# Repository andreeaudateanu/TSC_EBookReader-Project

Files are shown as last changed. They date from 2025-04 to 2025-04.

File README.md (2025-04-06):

# Proiect TSC - E-Book Reader
## Udățeanu Andreea-Laura

Acest proiect reprezinta un sistem embedded de tip **E-Book Reader**, bazat pe microcontrollerul **ESP32-C6**. Dispozitivul este capabil sa afiseze continut text pe un ecran **E-Paper**, oferind o solutie cu consum redus de energie, ideala pentru citirea offline a documentelor. Sistemul include, de asemenea, functionalitati precum citire de pe card SD, afisare dinamica, butoane pentru control si conectivitate extinsa prin interfata I2C.

# Diagrama bloc

Diagrama Bloc

# Functionalitati Hardware

Proiectul utilizeaza microcontrollerul **ESP32-C6-WROOM-1-N8**, un modul avansat cu suport pentru **Wi-Fi 6**, **Bluetooth Low Energy 5.0** si arhitectura **RISC-V**:

## Microcontrollerul ESP32-C6

- Modul avansat cu suport pentru **Wi-Fi 6**, **Bluetooth Low Energy 5.0** si arhitectura **RISC-V**
- **Interfete:** SPI, I2C, UART, USB, PWM, GPIO
	- **SPI (Serial Peripheral Interface):** este utilizat pentru comunicatia rapida cu dispozitive precum E-Paper Display-ul, memoria NOR Flash si cardul microSD.
	- **I2C (Inter-Integrated Circuit):** este o magistrala seriala bidirectionala cu doi pini (SDA si SCL), folosita pentru conectarea senzorului BME688, RTC-ului DS3231SN si monitorului de baterie MAX17048.
	- **UART (Universal Asynchronous Receiver/Transmitter):** interfata seriala folosita pentru comunicatie cu terminalul serial (TX/RX).
	- **GPIO (General Purpose Input/Output):** pini de uz general configurati ca intrare/iesire digitala – utilizati pentru butoane, controlul ecranului E-Ink, etc.

- **Caracteristici speciale:** ofera suport pentru moduri de economisire (deep sleep)
- **Conexiuni:** Interfata centrala – conecteaza toate modulele externe din cadrul proiectului(E-Paper, SD card, senzori, RTC, memorie NOR Flash, etc.)

## Alimentare si protectie

### MAX17048 – Monitorizare nivel de baterie Li-Po
- **Comunicare:** prin interfata I2C cu ESP32-C6 (SCL, SDA)
- **Iesire:** are la iesire un semnal ALERT pentru nivel critic baterie

### MCP73831 – Controller de incarcare a bateriei Li-Po
- **Incarcare:** utilizeaza o celula Li-Po prin USB (VBUS) → 4.2V
- **Curent de incarcare:** pana la 500 mA
- **LED-uri:** care indica starea de incarcare (CHG_LED)

### XC6220A331MR-G – Regulator de tensiune LDO
- Primeste la intrare 5V prin USB (VBUS), iar la iesire transmite o tensiune de 3.3V
- **Curent maxim:** 200 mA
- **Consum standby:** <1 µA

### Conector USB-C si Protectie ESD
- **Conector USB-C:** utilizat atat pentru alimentarea dispozitivului (VBUS) cat si pentru comunicatie USB cu microcontrollerul ESP32-C6.

- **Protectie ESD:** implementata pe liniile de date si alimentare folosind diode TVS dedicate:
USBLC6-2SC6Y – protejeaza liniile D+ si D−. PMF0501 – asigura protectie suplimentara pe linia de alimentare VBUS.
- **Utilizare:** permite incarcarea bateriei prin controllerul MCP73831, dar si programarea/diagnosticarea ESP32-C6 fara conexiuni suplimentare.

## Stocare

### SD Card
- **Functie:** citire/scriere a fisierelor E-Book din cardul microSD
- **Interfata:** SPI partajata cu E-Paper
- **Semnale:** SS_SD, MOSI, MISO, SCK
- **Slot:** 112A-TAAR-R03

### W25Q512JVEIQ – Memorie NOR Flash externa 64MB
- **Capacitate:** 64 MB
- **Interfata:** conectata la magistrala SPI (nu partajeaza cu E-Paper)
- **Semnale:** FLASH_CS, MOSI, MISO, SCK
- **Functie:** stocare fonturi, imagini, firmware, configurari

## Afisaj E-Paper

- Interfete SPI si GPIO dedicate, avand semnale precum: CS (EPD_CS), DC (EPD_DC), RST (EPD_RST), BUSY (EPD_BUSY), MOSI, SCK  
## **Header special EPD** cu 20 pini
## **Controlul alimentarii EPD:** 
Permite microcontrollerului sa activeze sau sa dezactiveze alimentarea modulului E-Paper pentru a economisi energie, avand la iesire o tensiune de 3V3
## **Selectare mod:** 
Comutator tip jumper pentru a selecta tipul de display (circuit EPD driver dedicat)
- Consum 0 in standby, ideal pentru afisaj static

## Senzor de Mediu BME688
- **Functionalitati:** temperatura, umiditate, presiune, calitate aer (VOC)
- **Interfata:** I2C
- **Pini:** SDA, SCL legati la magistrala I2C comuna
- **Tensiune de alimentare:** 3.3V

## Modul RTC – DS3231SN
- **Functie:** surprinde timpul real cu precizie ±2ppm, avand suport deep sleep
- **Conexiune:** I2C – partajeaza pinii SDA/SCL cu senzorul BME688 si cu monitorizatorul de baterie MAX17048
- **Iesiri:** semnal 32kHz si semnal de intrerupere (INT_RTC)
- **Alimentare:** 3.3V, avand si backup intern (capacitor)

## Functii de control, reset si protectie

### Butoane de Control
- **BOOT / RESET si IO/CHANGE personalizat:** conectate pe GPIO cu retele RC
- **Functii:** BOOT: initializare microcontroller in modul bootloader, RESET: resetare generala a sistemului si IO/CHANGE: buton suplimentare pentru interactiuni custom de tipul schimbarii paginii, a meniului, etc.

### BD5229G-TR – Voltage Supervisor
- **Rol:** detecteaza scaderile de tensiune (brown-out) sub un anumit prag critic si genereaza automat un semnal de rest
- **Asigura o pornirea sigura a sistemului

### Protectii ESD si Interfete Extensibile

- **Linii protejate:** toate magistralele sensibile – USB, SPI, I2C si GPIO – sunt protejate impotriva descarcarilor electrostatice (ESD) prin diode (ex: **USBLC6-2SC6Y**, **PGB1010603MR**, **MBR0530**).
- **Conector Qwiic / Stemma QT:** ofera o interfata I2C standard (3.3V, GND, SDA, SCL) pentru extinderea rapida a sistemului cu senzori si periferice de la SparkFun sau Adafruit, fara necesitatea lipirii.
- **Paduri de test:** sunt incluse pe PCB pentru depanare usoara, verificari de semnal si programare.

### Consum de energie estimativ

| Componenta | Consum aproximativ |
|:---|:---|
| ESP32-C6 | 120–150 mA |
| E-Paper Display | 20–40 mA |
| Senzor BME688 | 1–2 mA |
| RTC DS3231SN | 200 µA |
| SD Card | 40–100 mA |
| MAX17048 | 50 µA |
| NOR Flash (W25Q512JVEIQ)  | 20 mA |
| Total sistem - mod activ  | aprob. 300 mA |
| Total sistem - deep sleep | max. 10 µA |

Daca nu sunt dezactivate toate modulele fizic (cu MOSFET sau power gate), deep sleep-ul poate ajunge usor la 1–2 mA, deci <10 µA este ideal si atins doar cu management riguros al energiei.

### Alocarea pinilor

## E-Paper Display

| Pin ESP32-C6 | Functie | Utilizare |
|---|---|---|
| IO3  (26) | EPD_BUSY | Semnalizează dacă ecranul este activ |
| IO5  (5) | EPD_DC | Schimba modul intre date și comanda |
| IO6  (6) | SCK | Linie de ceas SPI - transfer de date |
| IO7  (7) | MOSI | Trimitere date către ecran prin SPI |
| IO10 (11) | EPD_CS | Activare comunicație cu modulul EPD |
| IO23 (21) | EPD_RST | Resetare ecran |
| IO20 (18) | EPD_3V3_C | Control tensiune de alimentare 3V3 EPD  |

## Magistrala I2C (MAX17048, RTC DS3231, BME688)

| Pin ESP32-C6 | Functie | Utilizare |
|---|---|---|
| IO21 (19) | SDA | Linie de transmitere date I2C |
| IO22 (20) | SCL | Linie de ceas I2C |
| IO19 (17) | I2C_PW | Pornire/oprire senzori I2C |

## Modul RTC DS3231SN

| Pin ESP32-C6 | Functie | Utilizare |
|---|---|---|
| IO0 (8) | INT_RTC | Semnal de întrerupere RTC |
| IO1 (9) | 32KHz | Iesire ceas precis |
| IO18 (16) | RTC_RST | Resetare hardware al modulului RTC |

## USB
| Pin ESP32-C6 | Functie | Utilizare |
|---|---|---|
| IO12 (13) | USB_D- | Linia negativa de comunicatie USB |
| IO13 (14) | USB_D+ | Linia pozitiva de comunicatie USB |

## Seriala UART

| Pin ESP32-C6 | Functie | Utilizare |
|---|---|---|
| IO16 (25) | TX | Transmisie UART |
| IO17 (24) | RX | Receptie UART |

## SD Card

| Pin ESP32-C6 | Functie | Utilizare |
|---|---|---|
| IO2 (27) | MISO | Receptie date |
| IO4 (4) | SS_SD | Selectare modul SD |
| IO6 (6) | SCK | Ceas SPI |
| IO7 (7) | MOSI | Transmisie date |

## Memorie Externa NOR Flash 64MB

| Pin ESP32-C6 | Functie | Utilizare |
|---|---|---|
| IO11 (12) | FLASH_CS | Selectare chip NOR |
| IO2  (27) | MISO | Receptie date |
| IO6  (6) | SCK | Ceas SPI |
| IO7  (7) | MOSI | Transmisie date |

## Butoane

| Pin ESP32-C6 | Functie | Utilizare |
|---|---|---|
| EN (3) | RESET | Resetare microcontroller |
| IO8  (10) | IO/BOOT | Buton BOOT (în modul de programare) |
| IO15 (23) | IO/CHANGE | Buton custom pentru diverse actiuni |

## Alimentare si Masă

| Pin ESP32-C6 | Functie | Utilizare |
|---|---|---|
| Pin 2 | 3V3 | Alimentare principala la 3.3V |
| Pin 1 | GND | Conectare la masa |

## Bill of Materials

| Componenta | Link Cumpărare | Datasheet |
|---|---|---|
| Condensatoare Tantalum | [Buy](https://ro.mouser.com/ProductDetail/KYOCERA-AVX/TAJW107M010RNJ?qs=Wtp%252Bf%2FAeVqIH8v1VxV%252B1Rg%3D%3D) | [Datasheet](https://ro.mouser.com/datasheet/2/40/TAJ-3165264.pdf) |
| Rezistente R0402 | [Buy](https://store.comet.srl.ro/Search/?keywords=r0402#eyJpcHAiOiIyMCIsIm0iOiIiLCJrIjoicjA0MDIifQ%3D%3D) | [Datasheet](https://www.yageo.com/upload/media/product/products/datasheet/rchip/PYu-RC_Group_51_RoHS_L_12.pdf) |
| Condensatoare C0402 | [Buy](https://store.comet.srl.ro/CatalogueFarnell/Search/?keywords=c0402#eyJpcHAiOiIyMCIsImsiOiJjMDQwMiJ9) | [Datasheet](https://componentsearchengine.com/Datasheets/2/CC0402MRX5R5BB106.pdf) |
| 112A-TAAR-R03 | [Buy](https://store.comet.srl.ro/Catalogue/Product/43497/) | [Datasheet](https://www.snapeda.com/parts/112A-TAAR-R03/Attend/datasheet/) |
| SD0805S020S1R0 | [Buy](https://ro.mouser.com/ProductDetail/KYOCERA-AVX/SD0805S020S1R0?qs=jCA%252BPfw4LHbpkAoSnwrdjw%3D%3D) | [Datasheet](https://ro.mouser.com/datasheet/2/40/schottky-3165252.pdf) |
| MBR0530 | [Buy](https://ro.mouser.com/ProductDetail/onsemi-Fairchild/MBR0530?qs=VOMQJJE%252BBNniwJKcE3T43Q==) | [Datasheet](https://ro.mouser.com/datasheet/2/308/MBR0530_D-1810985.pdf) |
| CHG_LED | [Buy](https://ro.mouser.com/ProductDetail/Kingbright/KP-1608SURCK?qs=2JU0tDl2GZ3FuyEWfBV1%2Fg==) | [Datasheet](https://www.snapeda.com/parts/KP-1608SURCK/Kingbright/datasheet/) |
| USBLC6-2SC6Y | [Buy](https://ro.mouser.com/ProductDetail/STMicroelectronics/USBLC6-2SC6Y?qs=gNDSiZmRJS%2FOgDexvXkdow%3D%3D) | [Datasheet](https://ro.mouser.com/datasheet/2/389/usblc6_2sc6y-1852505.pdf) 
| PGB1010603MR | [Buy](https://www.digikey.com/en/products/detail/littelfuse-inc/PGB1010603MR/715755) | [Datasheet](https://www.littelfuse.com/assetdocs/pulseguard-esd-suppressors-pgb1-datasheet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) |
| ESP32-C6-WROOM-1-N8 | [Buy](https://ro.mouser.com/ProductDetail/Espressif-Systems/ESP32-C6-WROOM-1-N8?qs=8Wlm6%252BaMh8ST02Gmwp74cw%3D%3D) | [Datasheet](https://ro.mouser.com/datasheet/2/891/Espressif_ESP32_C6_WROOM_1__Datasheet_V0_1_PRELIMI-3239987.pdf) |
| DS3231SN | [Buy](https://store.comet.srl.ro/Catalogue/Product/47690/) | [Datasheet](https://ro.mouser.com/datasheet/2/609/DS3231-3421123.pdf) |
| BME680 | [Buy](https://ro.mouser.com/ProductDetail/Bosch-Sensortec/BME688?qs=IS%252B4QmGtzzqQoVDscqwx3A%3D%3D) | [Datasheet](https://ro.mouser.com/datasheet/2/783/bst_bme688_fl000-2307034.pdf) |
| MAX17048 | [Buy](https://ro.mouser.com/ProductDetail/Analog-Devices-Maxim-Integrated/MAX17048G%2bT10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) | [Datasheet](https://ro.mouser.com/datasheet/2/609/MAX17048_MAX17049-3469099.pdf) |
| MCP73831 | [Buy](https://ro.mouser.com/ProductDetail/Microchip-Technology/MCP73831T-2ATI-OT?qs=yUQqVecv4qsZbioEUu%252B83g%3D%3D) | [Datasheet](https://ro.mouser.com/datasheet/2/268/MCP73831_Family_Data_Sheet_DS20001984H-3441711.pdf) |
| BD5229G-TR | [Buy](https://www.digikey.com/en/products/detail/rohm-semiconductor/BD5229G-TR/3663792) | [Datasheet](https://fscdn.rohm.com/en/products/databook/datasheet/ic/power/voltage_detector/bd52xxg-e.pdf) |
| W25Q512JVEIQ | [Buy](https://ro.mouser.com/ProductDetail/Winbond/W25Q512JVEIQ?qs=l7cgNqFNU1jw6svr3at6tA%3D%3D) | [Datasheet](https://ro.mouser.com/datasheet/2/949/Winbond_W25Q512JV_Datasheet-3240039.pdf) |
| XC6220A331MR-G | [Buy](https://ro.mouser.com/ProductDetail/Torex-Semiconductor/XC6220A331MR-G?qs=AsjdqWjXhJ8ZSWznL1J0gg%3D%3D) | [Datasheet](https://ro.mouser.com/datasheet/2/760/xc6220-3371556.pdf) |
| USB4110-GF-A | [Buy](https://ro.mouser.com/ProductDetail/GCT/USB4110-GF-A?qs=KUoIvG%2F9IlYiZvIXQjyJeA%3D%3D) | [Datasheet](https://ro.mouser.com/datasheet/2/837/GCT_USB4110_Product_Drawing___20k_cycles-3455479.pdf) |
| FH34SRJ | [Buy](https://ro.mouser.com/ProductDetail/Hirose-Connector/FH34SRJ-24S-0.5SH99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) | [Datasheet](https://ro.mouser.com/datasheet/2/185/FH34SRJ_24S_0_5SH_99__CL0580_1255_6_99_2DDrawing_0-1615044.pdf) |
| QWIIC_RIGHT_ANGLE | [Buy](https://ro.mouser.com/ProductDetail/SparkFun/PRT-14417?qs=wd5RIQLrsJhgdz%2FpmZ%2F3GQ==) | [Datasheet](https://ro.mouser.com/datasheet/2/813/Qwiic_Connector_Datasheet-1223982.pdf) |
| Bobine 744043680 | [Buy](https://ro.mouser.com/ProductDetail/Wurth-Elektronik/744043680?qs=PGXP4M47uW6VkZq%252BkzjrHA%3D%3D) | [Datasheet](https://www.we-online.com/components/products/datasheet/744043680.pdf) |
| Si1308EDL-T1-GE3 | [Buy](https://www.digikey.com/en/products/detail/vishay-siliconix/SI1308EDL-T1-GE3/4876435) | [Datasheet](https://www.vishay.com/docs/63399/si1308edl.pdf) |
| PFMF.050.1 | [Buy](https://ro.mouser.com/ProductDetail/EPCOS-TDK/B72520T0350K062?qs=dEfas%2FXlABIszF52uu7vrg%3D%3D) | [Datasheet](https://www.tdk-electronics.tdk.com/inf/75/db/CTVS_14/Surge_protection_series.pdf) |
| DMG2305UX-7 | [Buy](https://www.digikey.com/en/products/detail/diodes-incorporated/DMG2305UX-7/4340666) | [Datasheet](https://www.diodes.com/assets/Datasheets/DMG2305UX.pdf) |
| SJ (Solder Jumpers) | [Buy](https://grabcad.com/library/solder-jumpers-1) | [Datasheet](https://grabcad.com/library/solder-jumpers-1) |
| Butoane | [Buy](https://industry.panasonic.com/global/en/products/control/switch/light-touch/number/evqpuj02k) | [Datasheet](https://industry.panasonic.com/global/en/downloads?tab=catalog&small_g_cd=203&part_no=EVQPUJ02K) |
| CPH3225A | [Buy](https://www.digikey.com/en/products/detail/seiko-instruments/CPH3225A/8692444) | [Datasheet](https://mm.digikey.com/Volume0/opasdata/d220001/medias/docus/6537/rev05-CPHCPM.pdf) |

## Concluzii si observatii privind realizarea designului hardware
- In realizarea designului am urmarit respectarea regulilor impuse de ERC si DRC specifice. Amplasarea componentelor a fost facuta tinand cont atat de documentatiile tehnice oferite (dimensiuni si recomadari de plasare a componentelor), cat si de considerente legate de rutare si functionare optima a dispozitivului.
- Pentru evitarea erorilor in cadrul PCB-ului, am ajustat dimensiunile unor footprint-uri si am corectat pad-urile pentru a indeplini regulile de buna functionare. Am folosit regulile din checklist-ul de proiectare (inclusiv asezarea condensatorilor de decuplare plasati cat mai aproape de pinii VCC ai circuitelor integrate).
- Am distribuit traseele atat pe stratul top, cat si pe stratul bottom, incercand sa obtin cat mai putine vias-uri pe traseele de alimentare, pentru a reduce posibilitatea unei caderea de tensiune. Am rutat traseele de alimentare cu o latime de 0.3 mm, traseele de semnal avand latime de 0.15 mm conform cerintelor.
- Test pad-urile au fost amplasate cat mai eficient in zone relevante, la marginea placii: langa Header-ul E-Paper-ului si langa microcontroller.
- Am orientat antena modulului ESP32-C6 spre exteriorul placii, iar sub aceasta a fost lasata o zona decupata, conform recomandarilor pentru functionare optima a conexiunii wireless.
- Am pozitionat componentele cat mai bine pentru a putea fi integrate in carcasa proiectata, urmarind atat potrivirea mecanica, cat si o utilizare eficienta a spatiului disponibil. Am amplasat bateria in zona libera ramasa, astfel incat sa nu se intersecteze cu alte componente.
- Am tinut cont de amplasarea elementelor in functie de conectorul USB-C pentru asigurarea compatibilitatii cu carcasa. Butoanele au fost plasate cat mai eficient pentru a permite accesul la acestea si integrarea cu carcasa.
- In ansamblu, designul rezultat respecta cerintele functionale si mecanice, existand un echilibru intre robustete si eficienta.

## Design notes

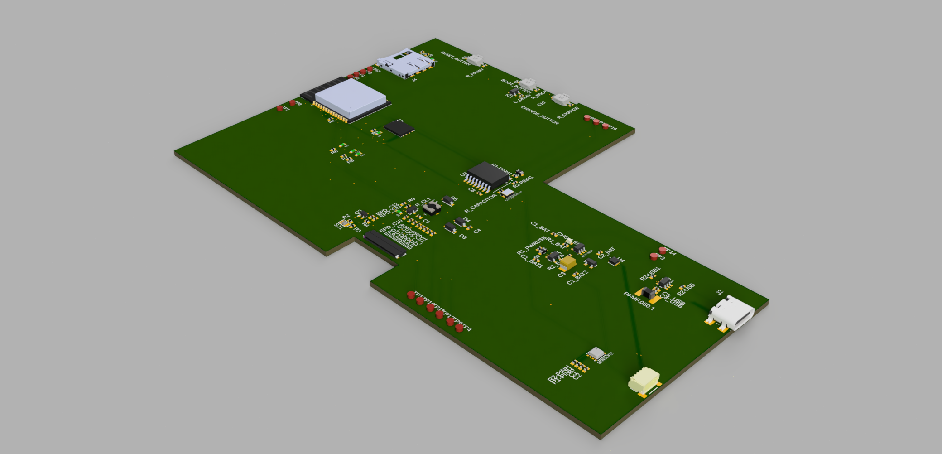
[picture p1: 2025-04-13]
Images/E-Book_Reader_Schematic_PLACUTA_HOME.png

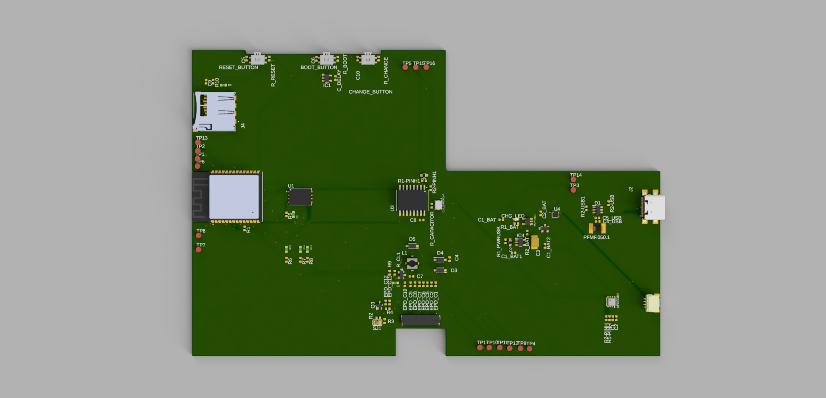
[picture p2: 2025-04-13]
Images/E-Book_Reader_Schematic_PLACUTA_TOP.png

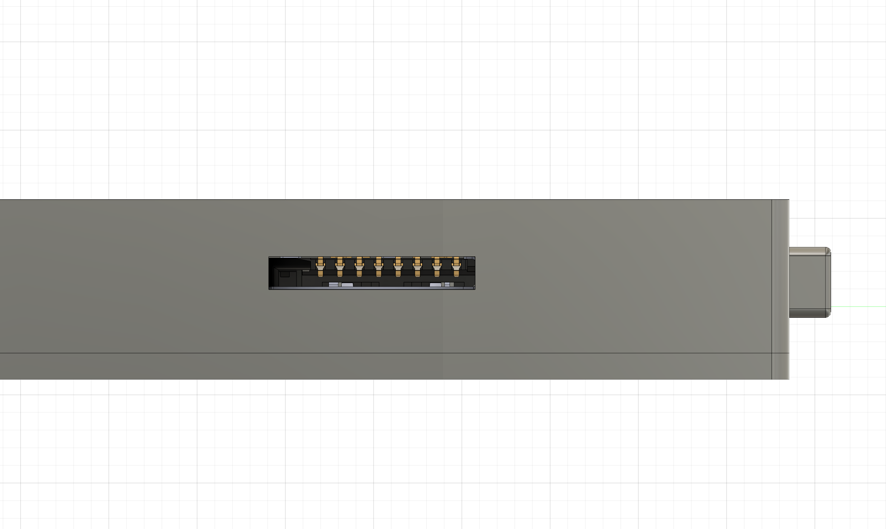
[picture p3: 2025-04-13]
Images/DeviceLeft.png

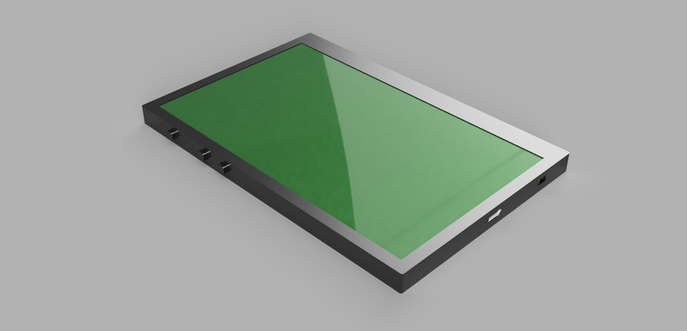
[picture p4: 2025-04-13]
Images/DeviceHome.png

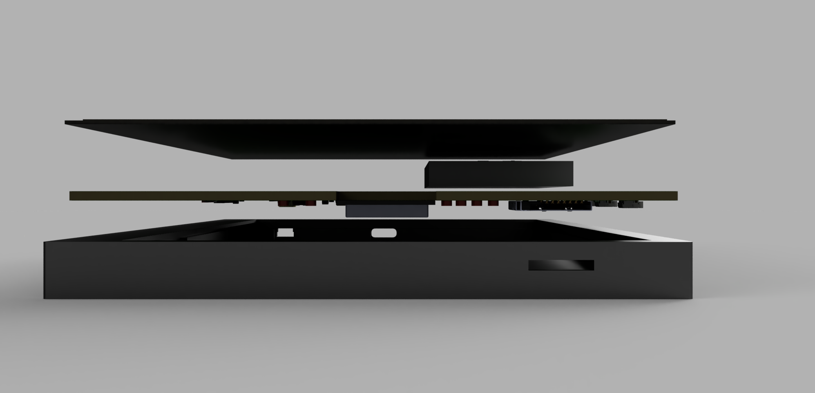
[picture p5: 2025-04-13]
Images/DeviceLayers.png

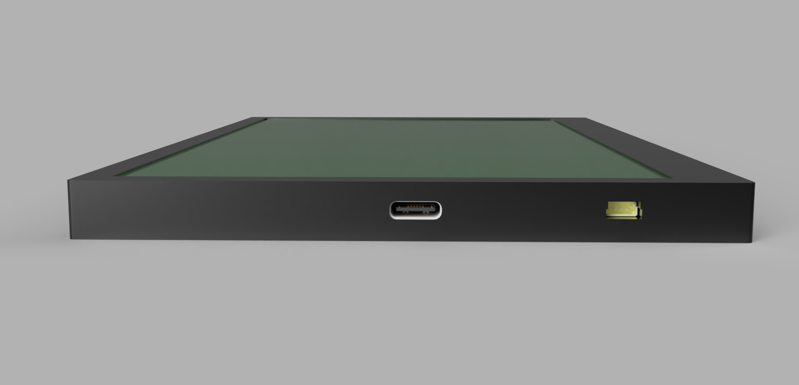
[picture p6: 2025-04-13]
Images/3D_RIGHT.png

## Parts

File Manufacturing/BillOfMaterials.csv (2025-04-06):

Part | Value | Device | Package | Description | ARROW_PART_NUMBER | ARROW_PRICE-STOCK | AVAILABILITY | CHECK_PRICES | COPYRIGHT | DESCRIPTION | HEIGHT | MANUFACTURER_NAME | MANUFACTURER_PART_NUMBER | MF | MFR_NAME | MOUSER_PART_NUMBER | MOUSER_PRICE-STOCK | MOUSER_TESTING_PART_NUMBER | MOUSER_TESTING_PRICE-STOCK | MP | PACKAGE | POPULARITY | PRICE | PROD_ID | PURCHASE-URL | SNAPEDA_LINK | SPICEMODEL | SPICEPREFIX | VALUE
BOOT_BUTTON | BUTTON_CUSYOMV1 | BUTTON_CUSYOMV1 | MYBUTTON
C1 | 100nF | EAGLE-LTSPICE_CC0402 | EAGLE-LTSPICE_C0402 | CAPACITOR, European symbol |  |  |  |  |  |  |  |  |  |  |  |  |  |  |  |  |  |  |  |  |  |  | NONE | C
C1_BAT | 4.7uF | EAGLE-LTSPICE_CC0402 | EAGLE-LTSPICE_C0402 | CAPACITOR, European symbol |  |  |  |  |  |  |  |  |  |  |  |  |  |  |  |  |  |  |  |  |  |  | NONE | C
C1_BAT1 | 4.7uF | EAGLE-LTSPICE_CC0402 | EAGLE-LTSPICE_C0402 | CAPACITOR, European symbol |  |  |  |  |  |  |  |  |  |  |  |  |  |  |  |  |  |  |  |  |  |  | NONE | C
C1_BAT2 | 4.7uF | EAGLE-LTSPICE_CC0402 | EAGLE-LTSPICE_C0402 | CAPACITOR, European symbol |  |  |  |  |  |  |  |  |  |  |  |  |  |  |  |  |  |  |  |  |  |  | NONE | C
C2 | 100nF | EAGLE-LTSPICE_CC0402 | EAGLE-LTSPICE_C0402 | CAPACITOR, European symbol |  |  |  |  |  |  |  |  |  |  |  |  |  |  |  |  |  |  |  |  |  |  | NONE | C
C2_BAT | 4.7uF | EAGLE-LTSPICE_CC0402 | EAGLE-LTSPICE_C0402 | CAPACITOR, European symbol |  |  |  |  |  |  |  |  |  |  |  |  |  |  |  |  |  |  |  |  |  |  | NONE | C
C3 | 100uF TANT | RCL_CPOL-EUCT3528 | RCL_CT3528 | POLARIZED CAPACITOR, European symbol |  |  |  |  |  |  |  |  |  |  |  |  |  |  |  |  |  | 0 |  |  |  |  |  | C
C4 | 4.7uF/25V | EAGLE-LTSPICE_CC0402 | EAGLE-LTSPICE_C0402 | CAPACITOR, European symbol |  |  |  |  |  |  |  |  |  |  |  |  |  |  |  |  |  |  |  |  |  |  | NONE | C
C4_USB | 100nF | ESP32_WROVER_EAGLE-LTSPICE_CC0402 | ESP32_WROVER_EAGLE-LTSPICE_C0402 | CAPACITOR, European symbol |  |  |  |  |  |  |  |  |  |  |  |  |  |  |  |  |  |  |  |  |  |  | NONE | C
C5 | 1uF | EAGLE-LTSPICE_CC0402 | EAGLE-LTSPICE_C0402 | CAPACITOR, European symbol |  |  |  |  |  |  |  |  |  |  |  |  |  |  |  |  |  |  |  |  |  |  | NONE | C
C5_USB | 4.7uF | ESP32_WROVER_EAGLE-LTSPICE_CC0402 | ESP32_WROVER_EAGLE-LTSPICE_C0402 | CAPACITOR, European symbol |  |  |  |  |  |  |  |  |  |  |  |  |  |  |  |  |  |  |  |  |  |  | NONE | C
C6 | 100nF | EAGLE-LTSPICE_CC0402 | EAGLE-LTSPICE_C0402 | CAPACITOR, European symbol |  |  |  |  |  |  |  |  |  |  |  |  |  |  |  |  |  |  |  |  |  |  | NONE | C
C7 | 10uF | EAGLE-LTSPICE_CC0402 | EAGLE-LTSPICE_C0402 | CAPACITOR, European symbol |  |  |  |  |  |  |  |  |  |  |  |  |  |  |  |  |  |  |  |  |  |  | NONE | C
C8 | 100nF | EAGLE-LTSPICE_CC0402 | EAGLE-LTSPICE_C0402 | CAPACITOR, European symbol |  |  |  |  |  |  |  |  |  |  |  |  |  |  |  |  |  |  |  |  |  |  | NONE | C
C9 | 100nF | ESP32_WROVER_EAGLE-LTSPICE_CC0402 | ESP32_WROVER_EAGLE-LTSPICE_C0402 | CAPACITOR, European symbol |  |  |  |  |  |  |  |  |  |  |  |  |  |  |  |  |  |  |  |  |  |  | NONE | C
C10 | 100nF | EAGLE-LTSPICE_CC0402 | EAGLE-LTSPICE_C0402 | CAPACITOR, European symbol |  |  |  |  |  |  |  |  |  |  |  |  |  |  |  |  |  |  |  |  |  |  | NONE | C
C10_SUPERCAP | CPH3225A | CPH3225A | CAPCP3225X100N | Cap 0.011F 3.3V 1210 Flat Check availability |  |  | Not in stock | https://www.snapeda.com/parts/CPH3225A/Seiko+Instruments/view-part/?ref=eda |  | 11 mF (EDLC) Supercapacitor 3.3 V 1210 (3225 Metric) - - |  |  |  | Seiko Instruments |  |  |  |  |  | CPH3225A | 1210 Seiko |  | None |  | https://www.snapeda.com/api/url_track_click_mouser/?unipart_id=562593&manufacturer=Seiko Instruments&part_name=CPH3225A&search_term=None | https://www.snapeda.com/parts/CPH3225A/Seiko+Instruments/view-part/?ref=snap
CHANGE_BUTTON | BUTTON_CUSYOMV1 | BUTTON_CUSYOMV1 | MYBUTTON
CHG_LED |  | ADAFRUIT_LEDCHIP-LED0603 | ADAFRUIT_CHIP-LED0603 | LED
C_DELAY | 100nF | EAGLE-LTSPICE_CC0402 | EAGLE-LTSPICE_C0402 | CAPACITOR, European symbol |  |  |  |  |  |  |  |  |  |  |  |  |  |  |  |  |  |  |  |  |  |  | NONE | C
D1 | USBLC6-2SC6Y | USBLC6-2SC6Y | SOT95P280X145-6N | Low Cap. ESD Protection Auto SOT-23-6 STMicroelectronics USBLC6-2SC6Y, Dual Uni-Directional TVS Diode Array, 6-Pin SOT-23 |  |  | In Stock | https://www.snapeda.com/parts/USBLC6-2SC6Y/STMicroelectronics/view-part/?ref=eda |  | 17V Clamp 5A (8/20µs) Ipp Tvs Diode Surface Mount SOT-23-6 |  |  |  | STMicroelectronics |  |  |  |  |  | USBLC6-2SC6Y | SOT-23-6 STMicroelectronics |  | None |  |  | https://www.snapeda.com/parts/USBLC6-2SC6Y/STMicroelectronics/view-part/?ref=snap
D2 | SD0805S020S1R0 | ESP32_WROVER_AVX---SD0805S020S1R0_AVX_SD0805S020S1R0_0_0 | ESP32_WROVER_AVX---SD0805S020S1R0_AVX_SD0805S020S1R0_0 | Schottky Barrier Rectifier Diode
D3 | MBR05301 | MBR05301 | SOD3716X135N | ON SEMICONDUCTOR - MBR0530 - DIODE, SCHOTTKY, 0.5A, 30V, SOD-123
D4 | MBR05301 | MBR05301 | SOD3716X135N | ON SEMICONDUCTOR - MBR0530 - DIODE, SCHOTTKY, 0.5A, 30V, SOD-123
D5 | MBR05301 | MBR05301 | SOD3716X135N | ON SEMICONDUCTOR - MBR0530 - DIODE, SCHOTTKY, 0.5A, 30V, SOD-123
D6 | PGB1010603MR | PGB1010603MR | DIOC1608X36N | Check availability |  |  | In Stock | https://www.snapeda.com/parts/PGB1010603MR/Littelfuse/view-part/?ref=eda |  | 150V (Typ) Clamp - Ipp Tvs Diode Surface Mount 0603 (1608 Metric) |  |  |  | Littelfuse Inc. |  |  |  |  |  | PGB1010603MR | 0603 Littelfuse Inc. |  | None |  | https://www.snapeda.com/api/url_track_click_mouser/?unipart_id=5659453&manufacturer=Littelfuse Inc.&part_name=PGB1010603MR&search_term=None | https://www.snapeda.com/parts/PGB1010603MR/Littelfuse/view-part/?ref=snap
D7 | SD0805S020S1R0 | ESP32_WROVER_AVX---SD0805S020S1R0_AVX_SD0805S020S1R0_0_0 | ESP32_WROVER_AVX---SD0805S020S1R0_AVX_SD0805S020S1R0_0 | Schottky Barrier Rectifier Diode
D8 | PGB1010603MR | PGB1010603MR | DIOC1608X36N | Check availability |  |  | In Stock | https://www.snapeda.com/parts/PGB1010603MR/Littelfuse/view-part/?ref=eda |  | 150V (Typ) Clamp - Ipp Tvs Diode Surface Mount 0603 (1608 Metric) |  |  |  | Littelfuse Inc. |  |  |  |  |  | PGB1010603MR | 0603 Littelfuse Inc. |  | None |  | https://www.snapeda.com/api/url_track_click_mouser/?unipart_id=5659453&manufacturer=Littelfuse Inc.&part_name=PGB1010603MR&search_term=None | https://www.snapeda.com/parts/PGB1010603MR/Littelfuse/view-part/?ref=snap
D9 | PGB1010603MR | PGB1010603MR | DIOC1608X36N | Check availability |  |  | In Stock | https://www.snapeda.com/parts/PGB1010603MR/Littelfuse/view-part/?ref=eda |  | 150V (Typ) Clamp - Ipp Tvs Diode Surface Mount 0603 (1608 Metric) |  |  |  | Littelfuse Inc. |  |  |  |  |  | PGB1010603MR | 0603 Littelfuse Inc. |  | None |  | https://www.snapeda.com/api/url_track_click_mouser/?unipart_id=5659453&manufacturer=Littelfuse Inc.&part_name=PGB1010603MR&search_term=None | https://www.snapeda.com/parts/PGB1010603MR/Littelfuse/view-part/?ref=snap
D10 | PGB1010603MR | PGB1010603MR | DIOC1608X36N | Check availability |  |  | In Stock | https://www.snapeda.com/parts/PGB1010603MR/Littelfuse/view-part/?ref=eda |  | 150V (Typ) Clamp - Ipp Tvs Diode Surface Mount 0603 (1608 Metric) |  |  |  | Littelfuse Inc. |  |  |  |  |  | PGB1010603MR | 0603 Littelfuse Inc. |  | None |  | https://www.snapeda.com/api/url_track_click_mouser/?unipart_id=5659453&manufacturer=Littelfuse Inc.&part_name=PGB1010603MR&search_term=None | https://www.snapeda.com/parts/PGB1010603MR/Littelfuse/view-part/?ref=snap
D11 | PGB1010603MR | PGB1010603MR | DIOC1608X36N | Check availability |  |  | In Stock | https://www.snapeda.com/parts/PGB1010603MR/Littelfuse/view-part/?ref=eda |  | 150V (Typ) Clamp - Ipp Tvs Diode Surface Mount 0603 (1608 Metric) |  |  |  | Littelfuse Inc. |  |  |  |  |  | PGB1010603MR | 0603 Littelfuse Inc. |  | None |  | https://www.snapeda.com/api/url_track_click_mouser/?unipart_id=5659453&manufacturer=Littelfuse Inc.&part_name=PGB1010603MR&search_term=None | https://www.snapeda.com/parts/PGB1010603MR/Littelfuse/view-part/?ref=snap
D12 | PGB1010603MR | PGB1010603MR | DIOC1608X36N | Check availability |  |  | In Stock | https://www.snapeda.com/parts/PGB1010603MR/Littelfuse/view-part/?ref=eda |  | 150V (Typ) Clamp - Ipp Tvs Diode Surface Mount 0603 (1608 Metric) |  |  |  | Littelfuse Inc. |  |  |  |  |  | PGB1010603MR | 0603 Littelfuse Inc. |  | None |  | https://www.snapeda.com/api/url_track_click_mouser/?unipart_id=5659453&manufacturer=Littelfuse Inc.&part_name=PGB1010603MR&search_term=None | https://www.snapeda.com/parts/PGB1010603MR/Littelfuse/view-part/?ref=snap
EPD_C1 | 1uF/50V | EAGLE-LTSPICE_CC0402 | EAGLE-LTSPICE_C0402 | CAPACITOR, European symbol |  |  |  |  |  |  |  |  |  |  |  |  |  |  |  |  |  |  |  |  |  |  | NONE | C
EPD_C2 | 1uF/50V | EAGLE-LTSPICE_CC0402 | EAGLE-LTSPICE_C0402 | CAPACITOR, European symbol |  |  |  |  |  |  |  |  |  |  |  |  |  |  |  |  |  |  |  |  |  |  | NONE | C
EPD_C5 | 0.1uF/50V | EAGLE-LTSPICE_CC0402 | EAGLE-LTSPICE_C0402 | CAPACITOR, European symbol |  |  |  |  |  |  |  |  |  |  |  |  |  |  |  |  |  |  |  |  |  |  | NONE | C
EPD_C6 | 1uF/50V | EAGLE-LTSPICE_CC0402 | EAGLE-LTSPICE_C0402 | CAPACITOR, European symbol |  |  |  |  |  |  |  |  |  |  |  |  |  |  |  |  |  |  |  |  |  |  | NONE | C
EPD_C7 | 1uF/50V | EAGLE-LTSPICE_CC0402 | EAGLE-LTSPICE_C0402 | CAPACITOR, European symbol |  |  |  |  |  |  |  |  |  |  |  |  |  |  |  |  |  |  |  |  |  |  | NONE | C
EPD_C8 | 1uF/50V | EAGLE-LTSPICE_CC0402 | EAGLE-LTSPICE_C0402 | CAPACITOR, European symbol |  |  |  |  |  |  |  |  |  |  |  |  |  |  |  |  |  |  |  |  |  |  | NONE | C
EPD_C9 | 1uF/50V | EAGLE-LTSPICE_CC0402 | EAGLE-LTSPICE_C0402 | CAPACITOR, European symbol |  |  |  |  |  |  |  |  |  |  |  |  |  |  |  |  |  |  |  |  |  |  | NONE | C
EPD_C10 | 1uF/50V | EAGLE-LTSPICE_CC0402 | EAGLE-LTSPICE_C0402 | CAPACITOR, European symbol |  |  |  |  |  |  |  |  |  |  |  |  |  |  |  |  |  |  |  |  |  |  | NONE | C
EPD_C11 | 1uF/50V | EAGLE-LTSPICE_CC0402 | EAGLE-LTSPICE_C0402 | CAPACITOR, European symbol |  |  |  |  |  |  |  |  |  |  |  |  |  |  |  |  |  |  |  |  |  |  | NONE | C
EPD_C12 | 1uF/50V | EAGLE-LTSPICE_CC0402 | EAGLE-LTSPICE_C0402 | CAPACITOR, European symbol |  |  |  |  |  |  |  |  |  |  |  |  |  |  |  |  |  |  |  |  |  |  | NONE | C
IC1 | BD5229G-TR | BD5229G-TR | SOT95P280X125-5N | Voltage Detector with Adjustable Delay Time: CMOS processes are utilized to develop high precision, low current consumption CMOS reset ICs that allow arbitrary setting of the delay time. The extensive lineup includes both Nch Open Drain and CMOS output types in a wide range of detection voltages (from 2.3V to 6.0V, in 0.1V steps), enabling selection of the ideal solution based on customer requirements. In addition, the entire series is of course both lead-free and RoHS-compliant. |  |  |  |  |  | Voltage Detector with Adjustable Delay Time: CMOS processes are utilized to develop high precision | low current consumption CMOS reset ICs that allow arbitrary setting of the delay time. The extensive lineup includes both Nch Open Drain and CMOS output types in a wide range of detection voltages (from 2.3V to 6.0V | in 0.1V steps) | enabling selection of the ideal solution based on customer requirements. In addition | the entire series is of course both lead-free and RoHS-compliant. | 1.25mm | ROHM Semiconductor | BD5229G-TR |  |  | 755-BD5229G-TR | https://www.mouser.co.uk/ProductDetail/ROHM-Semiconductor/BD5229G-TR?qs=4kLU8WoGk0vvnhrrYwdszw%3D%3D
IC4 | XC6220A331MR-G | XC6220A331MR-G | SOT95P280X120-5N | LDO Voltage Regulators |  |  |  |  |  | LDO Voltage Regulators | 1.2mm | Torex | XC6220A331MR-G |  |  | 865-XC6220A331MR-G | https://www.mouser.co.uk/ProductDetail/Torex-Semiconductor/XC6220A331MR-G?qs=AsjdqWjXhJ8ZSWznL1J0gg%3D%3D
J1 | FH34SRJ-24S-0.5SH_99_ | FH34SRJ-24S-0.5SH_99_ | FH34SRJ24S05SH99 | (0.50mm) Surface Mount, Right Angle |  |  |  |  |  | 24 Position FFC | FPC Connector Contacts | (0.50mm) Surface Mount | Right Angle | 1.1mm | Hirose | FH34SRJ-24S-0.5SH(99) |  |  | 798-FH34SRJ24S05SH99 | https://www.mouser.co.uk/ProductDetail/Hirose-Connector/FH34SRJ-24S-0.5SH99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
J2 | SAMACSYS_PARTS_USB4110-GF-A | SAMACSYS_PARTS_USB4110-GF-A | SAMACSYS_PARTS_USB4110GFA | CONN USB 2.0 TYPE-C R/A SMT |  |  |  |  |  | CONN USB 2.0 TYPE-C R/A SMT | 3.26mm | GCT (GLOBAL CONNECTOR TECHNOLOGY) | USB4110-GF-A |  |  | 640-USB4110-GF-A | https://www.mouser.co.uk/ProductDetail/GCT/USB4110-GF-A?qs=KUoIvG%2F9IlYiZvIXQjyJeA%3D%3D
J3 | QWIIC_RIGHT_ANGLE | QWIIC_CONNECTORJS-1MM | JST04_1MM_RA | SparkFun I2C Standard Qwiic Connector |  |  |  |  |  |  |  |  |  |  |  |  |  |  |  |  |  |  |  | CONN-13694 |  |  |  |  | QWIIC_RIGHT_ANGLE
J4 | 112A-TAAR-R03_ATTEND | 112A-TAAR-R03_ATTEND | 112ATAARR03ATTEND | Micro SD Card Socket, Push-Push Type, Top Mount, SMT, H=1.83mm, 10u |  |  |  |  |  | Micro SD Card Socket | Push-Push Type | Top Mount | SMT | H=1.83mm | 10u | 1.9mm | ATTEND | 112A-TAAR-R03 ATTEND
L1 | 68uH | 744043680IND_4828-WE-TPC_WRE | IND_4828-WE-TPC_WRE |  |  |  |  |  | Copyright (C) 2024 Ultra Librarian. All rights reserved. |  |  |  | 744043680 |  | Wurth Electronics
MCP73831 | ESP32_WROVER_SPARKFUN-IC-POWER_MCP73831 | ESP32_WROVER_SPARKFUN-IC-POWER_MCP73831 | ESP32_WROVER_SPARKFUN-IC-POWER_SOT23-5 | MCP73831T Li-Ion, Li-Pol Controller |  |  |  |  |  |  |  |  |  |  |  |  |  |  |  |  |  |  |  | IC-09995
PFMF.050.1 | ESP32C6_VARISTORCN1812 | ESP32C6_VARISTORCN1812 | ESP32C6_VARISTOR_CT/CN1812 | VARISTOR |  |  |  |  |  |  |  |  |  |  |  |  |  |  |  |  |  | 0
Q1 | 20V/4.2A/52mΩ/1.4W | ESP32_WROVER_SPARKFUN-DISCRETESEMI_MOSFET_PCH-DMG2305UX-7 | ESP32_WROVER_SPARKFUN-DISCRETESEMI_SOT23-3 | P-channel MOSFETs |  |  |  |  |  |  |  |  |  |  |  |  |  |  |  |  |  |  |  | TRAN-14388 |  |  |  |  | 20V/4.2A/52mΩ/1.4W
Q2 | 20V/4.2A/52mΩ/1.4W | ESP32_WROVER_SPARKFUN-DISCRETESEMI_MOSFET_PCH-DMG2305UX-7 | ESP32_WROVER_SPARKFUN-DISCRETESEMI_SOT23-3 | P-channel MOSFETs |  |  |  |  |  |  |  |  |  |  |  |  |  |  |  |  |  |  |  | TRAN-14388 |  |  |  |  | 20V/4.2A/52mΩ/1.4W
Q3 | SI1308EDL-T1-GE3 | SI1308EDL-T1-GE3 | SOT65P210X110-3N | MOSFET N-Ch 30V 1.5A TrenchFET SC70 Vishay Si1308EDL-T1-GE3 N-channel MOSFET Transistor, 1.5 A, 30 V, 3-Pin SC-70 |  |  | In Stock | https://www.snapeda.com/parts/SI1308EDL-T1-GE3/Vishay+Siliconix/view-part/?ref=eda |  | Si1308EDL-T1-GE3 N-channel MOSFET Transistor | 1.5 A | 30 V | 3-Pin SC-70 | Siliconix / Vishay SI1308EDL-T1-GE3 |  |  |  | Vishay Siliconix |  |  |  |  |  | SI1308EDL-T1-GE3 | SOT-323 Vishay Semiconductor |  | None |  | https://www.snapeda.com/api/url_track_click_mouser/?unipart_id=274603&manufacturer=Vishay Siliconix&part_name=SI1308EDL-T1-GE3&search_term=None | https://www.snapeda.com/parts/SI1308EDL-T1-GE3/Vishay+Siliconix/view-part/?ref=snap
R1 | 10K | ESP32_WROVER_EAGLE-LTSPICE_RR0402 | ESP32_WROVER_EAGLE-LTSPICE_R0402 | RESISTOR, European symbol |  |  |  |  |  |  |  |  |  |  |  |  |  |  |  |  |  |  |  |  |  |  | NONE | R
R1-PINH | 10K | ESP32_WROVER_EAGLE-LTSPICE_RR0402 | ESP32_WROVER_EAGLE-LTSPICE_R0402 | RESISTOR, European symbol |  |  |  |  |  |  |  |  |  |  |  |  |  |  |  |  |  |  |  |  |  |  | NONE | R
R1-PINH1 | 10K | ESP32_WROVER_EAGLE-LTSPICE_RR0402 | ESP32_WROVER_EAGLE-LTSPICE_R0402 | RESISTOR, European symbol |  |  |  |  |  |  |  |  |  |  |  |  |  |  |  |  |  |  |  |  |  |  | NONE | R
R1_BAT | 200 | ESP32_WROVER_EAGLE-LTSPICE_RR0402 | ESP32_WROVER_EAGLE-LTSPICE_R0402 | RESISTOR, European symbol |  |  |  |  |  |  |  |  |  |  |  |  |  |  |  |  |  |  |  |  |  |  | NONE | R
R1_PWRUSB | 100K | ESP32_WROVER_EAGLE-LTSPICE_RR0402 | ESP32_WROVER_EAGLE-LTSPICE_R0402 | RESISTOR, European symbol |  |  |  |  |  |  |  |  |  |  |  |  |  |  |  |  |  |  |  |  |  |  | NONE | R
R2 | 2.2 | ESP32_WROVER_EAGLE-LTSPICE_RR0402 | ESP32_WROVER_EAGLE-LTSPICE_R0402 | RESISTOR, European symbol |  |  |  |  |  |  |  |  |  |  |  |  |  |  |  |  |  |  |  |  |  |  | NONE | R
R2-PINH | 10K | ESP32_WROVER_EAGLE-LTSPICE_RR0402 | ESP32_WROVER_EAGLE-LTSPICE_R0402 | RESISTOR, European symbol |  |  |  |  |  |  |  |  |  |  |  |  |  |  |  |  |  |  |  |  |  |  | NONE | R
R2-PINH1 | 10K | ESP32_WROVER_EAGLE-LTSPICE_RR0402 | ESP32_WROVER_EAGLE-LTSPICE_R0402 | RESISTOR, European symbol |  |  |  |  |  |  |  |  |  |  |  |  |  |  |  |  |  |  |  |  |  |  | NONE | R
R2-USB | 5K1 | ESP32_WROVER_EAGLE-LTSPICE_RR0402 | ESP32_WROVER_EAGLE-LTSPICE_R0402 | RESISTOR, European symbol |  |  |  |  |  |  |  |  |  |  |  |  |  |  |  |  |  |  |  |  |  |  | NONE | R
R2-USB1 | 5k1 | ESP32_WROVER_EAGLE-LTSPICE_RR0402 | ESP32_WROVER_EAGLE-LTSPICE_R0402 | RESISTOR, European symbol |  |  |  |  |  |  |  |  |  |  |  |  |  |  |  |  |  |  |  |  |  |  | NONE | R
R2_BAT | 2K | ESP32_WROVER_EAGLE-LTSPICE_RR0402 | ESP32_WROVER_EAGLE-LTSPICE_R0402 | RESISTOR, European symbol |  |  |  |  |  |  |  |  |  |  |  |  |  |  |  |  |  |  |  |  |  |  | NONE | R
R3 | 0.47 | ESP32_WROVER_EAGLE-LTSPICE_RR0402 | ESP32_WROVER_EAGLE-LTSPICE_R0402 | RESISTOR, European symbol |  |  |  |  |  |  |  |  |  |  |  |  |  |  |  |  |  |  |  |  |  |  | NONE | R
R4 | 10K | ESP32_WROVER_EAGLE-LTSPICE_RR0402 | ESP32_WROVER_EAGLE-LTSPICE_R0402 | RESISTOR, European symbol |  |  |  |  |  |  |  |  |  |  |  |  |  |  |  |  |  |  |  |  |  |  | NONE | R
R5 | 10K | ESP32_WROVER_EAGLE-LTSPICE_RR0402 | ESP32_WROVER_EAGLE-LTSPICE_R0402 | RESISTOR, European symbol |  |  |  |  |  |  |  |  |  |  |  |  |  |  |  |  |  |  |  |  |  |  | NONE | R
R6 | 10K | ESP32_WROVER_EAGLE-LTSPICE_RR0402 | ESP32_WROVER_EAGLE-LTSPICE_R0402 | RESISTOR, European symbol |  |  |  |  |  |  |  |  |  |  |  |  |  |  |  |  |  |  |  |  |  |  | NONE | R
R7 | 10K | ESP32_WROVER_EAGLE-LTSPICE_RR0402 | ESP32_WROVER_EAGLE-LTSPICE_R0402 | RESISTOR, European symbol |  |  |  |  |  |  |  |  |  |  |  |  |  |  |  |  |  |  |  |  |  |  | NONE | R
R8 | 10K | ESP32_WROVER_EAGLE-LTSPICE_RR0402 | ESP32_WROVER_EAGLE-LTSPICE_R0402 | RESISTOR, European symbol |  |  |  |  |  |  |  |  |  |  |  |  |  |  |  |  |  |  |  |  |  |  | NONE | R
R9 | 10K | ESP32_WROVER_EAGLE-LTSPICE_RR0402 | ESP32_WROVER_EAGLE-LTSPICE_R0402 | RESISTOR, European symbol |  |  |  |  |  |  |  |  |  |  |  |  |  |  |  |  |  |  |  |  |  |  | NONE | R
R10 | 10K | ESP32_WROVER_EAGLE-LTSPICE_RR0402 | ESP32_WROVER_EAGLE-LTSPICE_R0402 | RESISTOR, European symbol |  |  |  |  |  |  |  |  |  |  |  |  |  |  |  |  |  |  |  |  |  |  | NONE | R
RESET_BUTTON | BUTTON_CUSYOMV1 | BUTTON_CUSYOMV1 | MYBUTTON
R_BOOT | 10K | ESP32_WROVER_EAGLE-LTSPICE_RR0402 | ESP32_WROVER_EAGLE-LTSPICE_R0402 | RESISTOR, European symbol |  |  |  |  |  |  |  |  |  |  |  |  |  |  |  |  |  |  |  |  |  |  | NONE | R
R_CAPACITOR | 15 | ESP32_WROVER_EAGLE-LTSPICE_RR0402 | ESP32_WROVER_EAGLE-LTSPICE_R0402 | RESISTOR, European symbol |  |  |  |  |  |  |  |  |  |  |  |  |  |  |  |  |  |  |  |  |  |  | NONE | R
R_CHANGE | 10K | ESP32_WROVER_EAGLE-LTSPICE_RR0402 | ESP32_WROVER_EAGLE-LTSPICE_R0402 | RESISTOR, European symbol |  |  |  |  |  |  |  |  |  |  |  |  |  |  |  |  |  |  |  |  |  |  | NONE | R
R_CL1 | 10K | ESP32_WROVER_EAGLE-LTSPICE_RR0402 | ESP32_WROVER_EAGLE-LTSPICE_R0402 | RESISTOR, European symbol |  |  |  |  |  |  |  |  |  |  |  |  |  |  |  |  |  |  |  |  |  |  | NONE | R
R_RESET | 10K | ESP32_WROVER_EAGLE-LTSPICE_RR0402 | ESP32_WROVER_EAGLE-LTSPICE_R0402 | RESISTOR, European symbol |  |  |  |  |  |  |  |  |  |  |  |  |  |  |  |  |  |  |  |  |  |  | NONE | R
SENSOR2 | BME688 | ESP32_WROVER_BME680_BME680 | ESP32_WROVER_BME680_PSON80P300X300X100-8N | Integrated Environmental Unit |  |  | Unavailable |  |  | Integrated Environmental Unit |  |  |  | Bosch Sensortec |  |  |  |  |  | BME680 | LGA-8 Bosch Tools |  | None
SJ1 |  | SJ | SJ | SMD solder JUMPER |  |  |  |  |  |  |  |  |  |  |  |  |  |  |  |  |  | 3
TP1 | TPTP20R | TP | TP20R | Test pad
TP2 | TP | TP | TP20R | Test pad
TP3 | TP | TP | TP20R | Test pad
TP4 | TP | TP | TP20R | Test pad
TP5 | TP | TP | TP20R | Test pad
TP6 | TP | TP | TP20R | Test pad
TP7 | TP | TP | TP20R | Test pad
TP8 | TP | TP | TP20R | Test pad
TP9 | TP | TP | TP20R | Test pad
TP10 | TP | TP | TP20R | Test pad
TP11 | TP | TP | TP20R | Test pad
TP12 | TP | TP | TP20R | Test pad
TP13 | TP | TP | TP20R | Test pad
TP14 | TP | TP | TP20R | Test pad
TP15 | TP | TP | TP20R | Test pad
TP16 | TP | TP | TP20R | Test pad
TP17 | TP | TP | TP20R | Test pad
U1 | W25Q512JVEIQ | W25Q512JVEIQ | SON127P600X800X80-9N | Check availability |  |  | In Stock | https://www.snapeda.com/parts/W25Q512JVEIQ/Winbond+Electronics/view-part/?ref=eda |  | FLASH - NOR Memory IC 512Mb (64M x 8) SPI - Quad I/O 133 MHz 8-WSON (8x6) |  |  |  | Winbond Electronics |  |  |  |  |  | W25Q512JVEIQ | Package |  | None |  |  | https://www.snapeda.com/parts/W25Q512JVEIQ/Winbond+Electronics/view-part/?ref=snap
U2 | ESP32-C6-WROOM-1-N8 | ESP32-C6-WROOM-1-N8 | XCVR_ESP32-C6-WROOM-1-N8 | Check availability |  |  | In Stock | https://www.snapeda.com/parts/ESP32-C6-WROOM-1-N8/Espressif+Systems/view-part/?ref=eda |  | Multiprotocol Modules ESP32-C6 module | Wi-Fi 6 in 2.4 GHz band | Bluetooth 5 | Zigbee 3.0 and Thread. ESP34-WROOM Compatible - ENGINEERING SAMPLE |  |  |  | Espressif Systems |  |  |  |  |  | ESP32-C6-WROOM-1-N8 | None |  | None |  |  | https://www.snapeda.com/parts/ESP32-C6-WROOM-1-N8/Espressif+Systems/view-part/?ref=snap
U3 | DS3231SN# | DS3231SN# | SOIC127P1032X265-16N | Real Time Clock Serial 16-Pin SOIC W T/R Check availability |  |  | In Stock | https://www.snapeda.com/parts/DS3231SN%23/Analog+Devices/view-part/?ref=eda |  | Extremely Accurate I²C-Integrated RTC/TCXO/Crystal |  |  |  | Analog Devices |  |  |  |  |  | DS3231SN# | SOIC-16 Maxim |  | None |  | https://www.snapeda.com/api/url_track_click_mouser/?unipart_id=99048&manufacturer=Analog Devices&part_name=DS3231SN#&search_term=None | https://www.snapeda.com/parts/DS3231SN%23/Analog+Devices/view-part/?ref=snap
U4 | MAX17048G+T10 | MAX17048G+T10 | SON50P200X200X80-9N | Check availability |  |  | In Stock | https://www.snapeda.com/parts/MAX17048G+T10/Analog+Devices/view-part/?ref=eda |  | 3µA 1-Cell/2-Cell Fuel Gauge with ModelGauge |  |  |  | Analog Devices |  |  |  |  |  | MAX17048G+T10 | TDFN-8 Maxim |  | None |  | https://www.snapeda.com/api/url_track_click_mouser/?unipart_id=329239&manufacturer=Analog Devices&part_name=MAX17048G+T10&search_term=None | https://www.snapeda.com/parts/MAX17048G+T10/Analog+Devices/view-part/?ref=snap

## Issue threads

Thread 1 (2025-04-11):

Probleme PCB

Vinti03, 2025-04-11:
Am atasat mai jos problemele pe care le-am gasit la nivelul PCB-ului.

Closed 2025-04-13.

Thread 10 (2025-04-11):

Componenta J4 nu are modelul 3D specific SD card reader

Vinti03, 2025-04-11:
In timp ce verificam porturile, am observat ca la componenta J4 lipseste interiorul specific de cititor de carduri SD si apoi am verificat si intradevar componenta nu avea modelul 3D specific 112A-TAAR-R03_ATTEND.

Closed 2025-04-13.

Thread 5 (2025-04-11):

Probleme schematic

Vinti03, 2025-04-11:
Am atasat mai jos problemele gasite la schematic.

Closed 2025-04-13.

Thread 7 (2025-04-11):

Numele condensatoarelor merg aranjate mai bine

Vinti03, 2025-04-11:
Am observat uitandu-ma la codensatoarele de la "E-Paper Display Header" ca numele lor pot fi puse astfel incat sa fie mai intuitiv care nume/valoare corespunde carui condensator de acolo.

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

Closed 2025-04-13.

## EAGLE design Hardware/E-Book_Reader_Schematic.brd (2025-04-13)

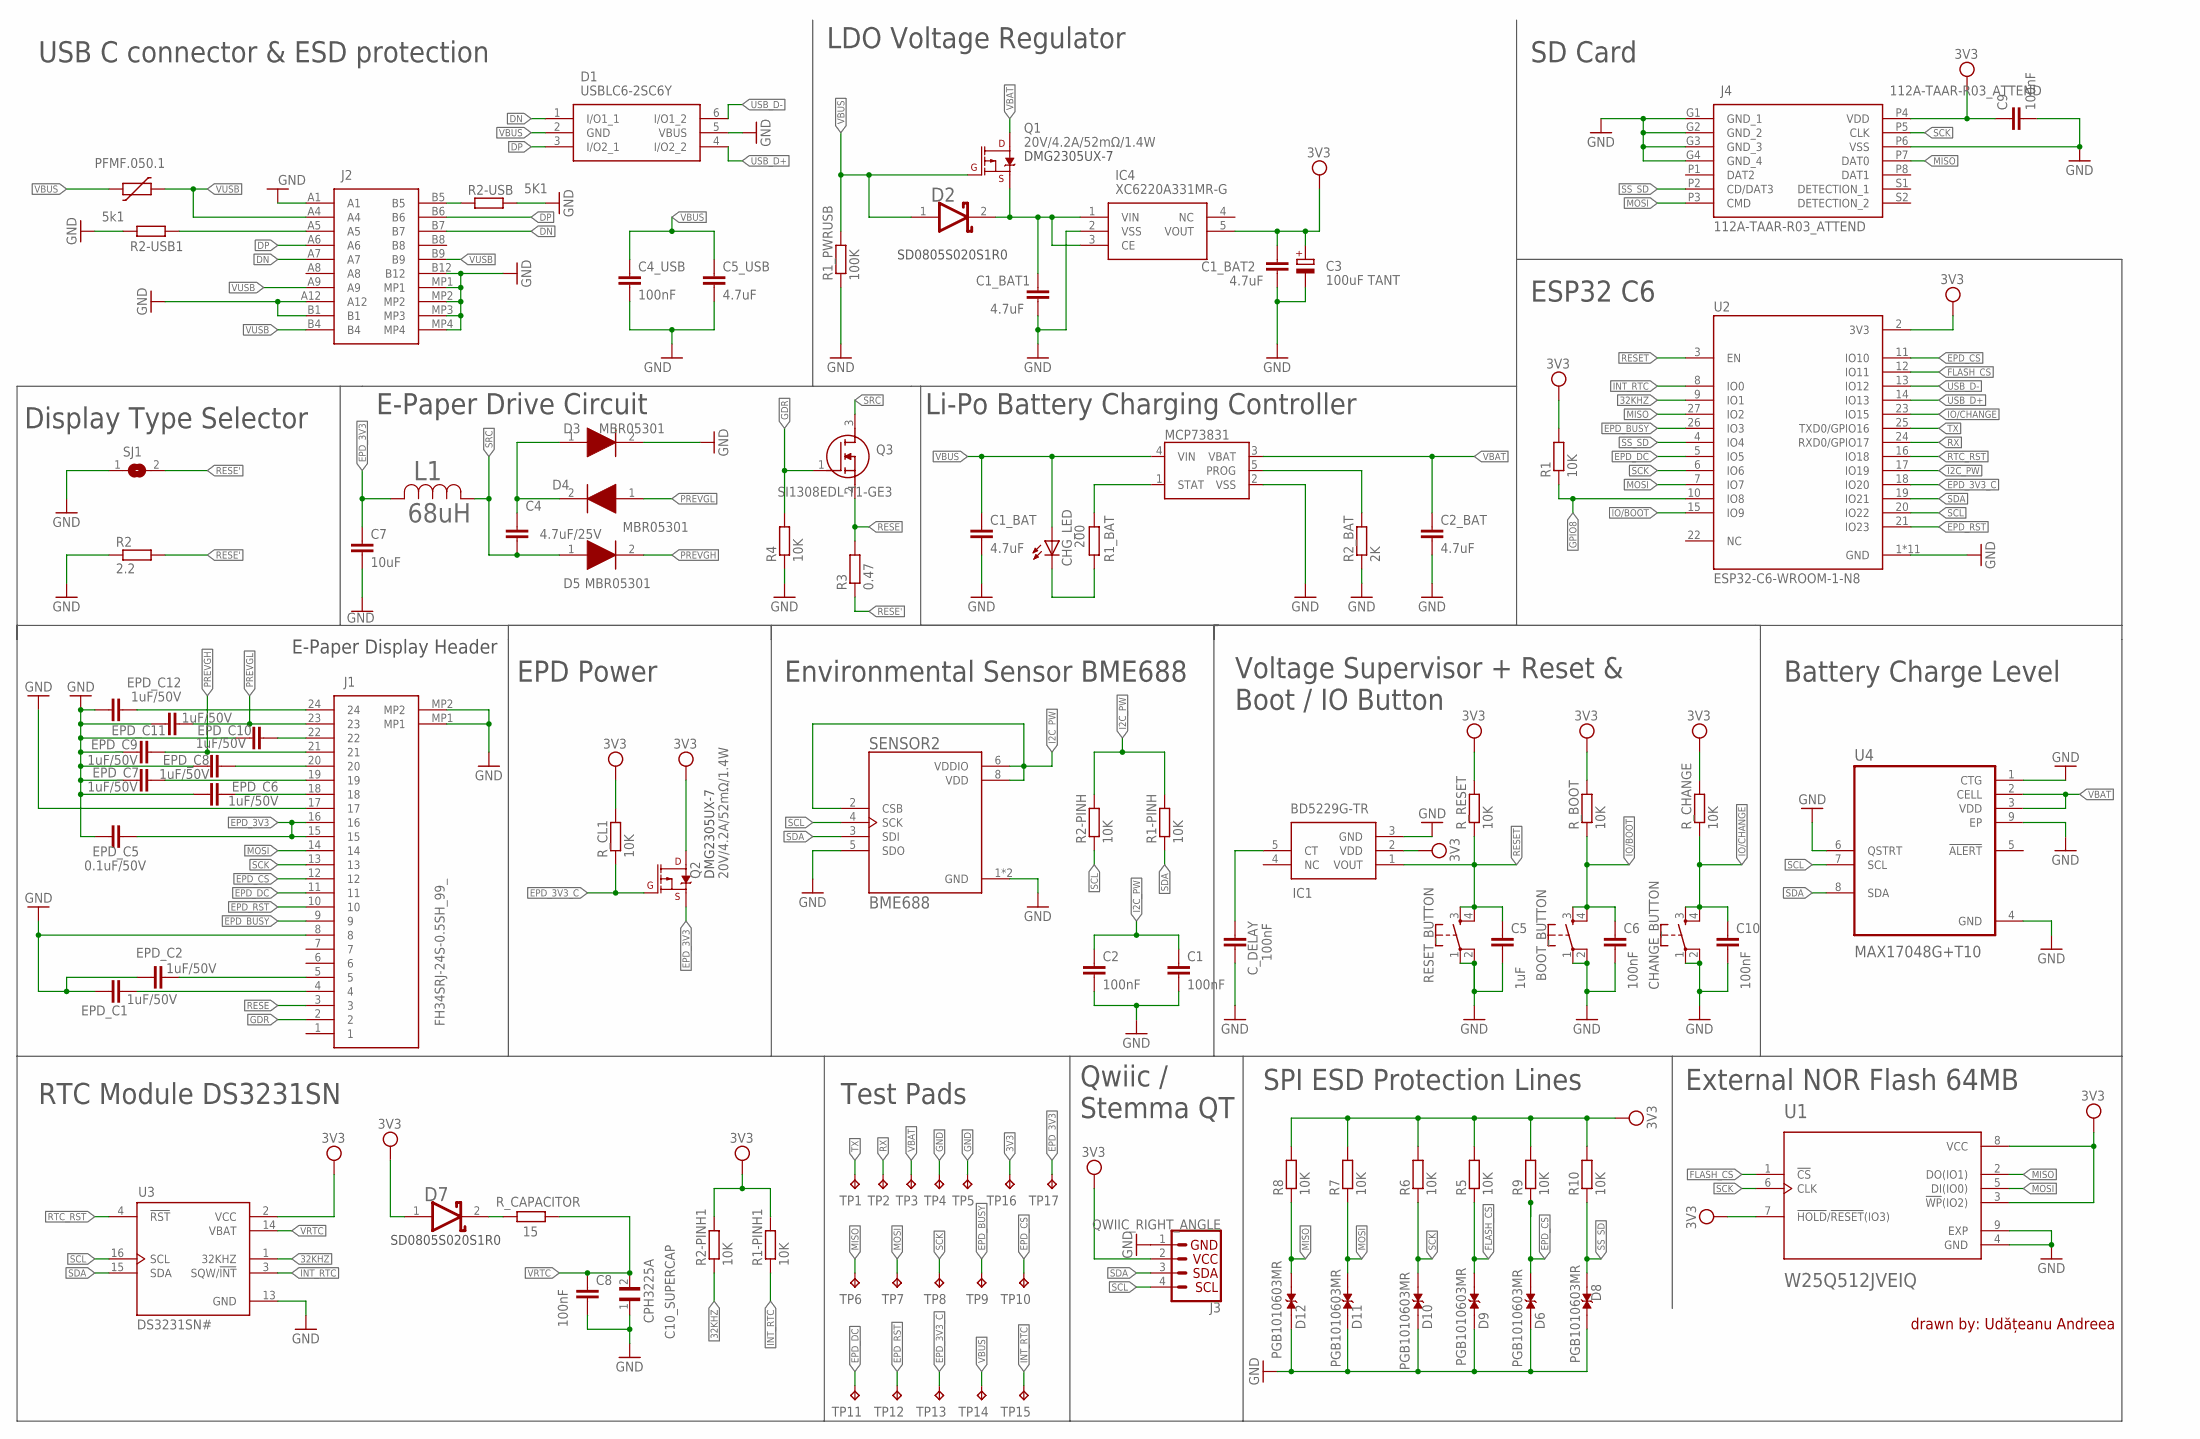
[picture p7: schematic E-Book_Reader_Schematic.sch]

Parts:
BOOT_BUTTON: BUTTON_CUSYOMV1; MYBUTTON
C1, C2, C6, C8, C10: 100nF; EAGLE-LTSPICE_C0402
C1_BAT, C1_BAT1, C1_BAT2, C2_BAT: 4.7uF; EAGLE-LTSPICE_C0402
C3: 100uF TANT; RCL_CT3528
C4: 4.7uF/25V; EAGLE-LTSPICE_C0402
C4_USB, C9: 100nF; ESP32_WROVER_EAGLE-LTSPICE_C0402
C5: 1uF; EAGLE-LTSPICE_C0402
C5_USB: 4.7uF; ESP32_WROVER_EAGLE-LTSPICE_C0402
C7: 10uF; EAGLE-LTSPICE_C0402
C10_SUPERCAP: CPH3225A; CAPCP3225X100N
CHANGE_BUTTON: BUTTON_CUSYOMV1; MYBUTTON
CHG_LED: ADAFRUIT_LEDCHIP-LED0603; ADAFRUIT_CHIP-LED0603
C_DELAY: 100nF; EAGLE-LTSPICE_C0402
D1: USBLC6-2SC6Y; SOT95P280X145-6N
D2, D7: SD0805S020S1R0; ESP32_WROVER_AVX---SD0805S020S1R0_AVX_SD0805S020S1R0_0
D3, D4, D5: MBR05301; SOD3716X135N
D6, D8, D9, D10, D11, D12: PGB1010603MR; DIOC1608X36N
EPD_C1, EPD_C2, EPD_C6, EPD_C7, EPD_C8, EPD_C9, EPD_C10, EPD_C11, EPD_C12: 1uF/50V; EAGLE-LTSPICE_C0402
EPD_C5: 0.1uF/50V; EAGLE-LTSPICE_C0402
IC1: BD5229G-TR; SOT95P280X125-5N
IC4: XC6220A331MR-G; SOT95P280X120-5N
J1: FH34SRJ-24S-0.5SH_99_; FH34SRJ24S05SH99
J2: SAMACSYS_PARTS_USB4110-GF-A; SAMACSYS_PARTS_USB4110GFA
J3: QWIIC_RIGHT_ANGLE; JST04_1MM_RA
J4: 112A-TAAR-R03_ATTEND; 112ATAARR03ATTEND
L1: 68uH; IND_4828-WE-TPC_WRE
MCP73831: ESP32_WROVER_SPARKFUN-IC-POWER_MCP73831; ESP32_WROVER_SPARKFUN-IC-POWER_SOT23-5
PFMF.050.1: ESP32C6_VARISTORCN1812; ESP32C6_VARISTOR_CT/CN1812
Q1, Q2: 20V/4.2A/52mΩ/1.4W; ESP32_WROVER_SPARKFUN-DISCRETESEMI_SOT23-3
Q3: SI1308EDL-T1-GE3; SOT65P210X110-3N
R1, R1-PINH, R1-PINH1, R2-PINH, R2-PINH1, R4, R5, R6, R7, R8, R9, R10: 10K; ESP32_WROVER_EAGLE-LTSPICE_R0402
R1_BAT: 200; ESP32_WROVER_EAGLE-LTSPICE_R0402
R1_PWRUSB: 100K; ESP32_WROVER_EAGLE-LTSPICE_R0402
R2: 2.2; ESP32_WROVER_EAGLE-LTSPICE_R0402
R2-USB: 5K1; ESP32_WROVER_EAGLE-LTSPICE_R0402
R2-USB1: 5k1; ESP32_WROVER_EAGLE-LTSPICE_R0402
R2_BAT: 2K; ESP32_WROVER_EAGLE-LTSPICE_R0402
R3: 0.47; ESP32_WROVER_EAGLE-LTSPICE_R0402
RESET_BUTTON: BUTTON_CUSYOMV1; MYBUTTON
R_BOOT: 10K; ESP32_WROVER_EAGLE-LTSPICE_R0402
R_CAPACITOR: 15; ESP32_WROVER_EAGLE-LTSPICE_R0402
R_CHANGE: 10K; ESP32_WROVER_EAGLE-LTSPICE_R0402
R_CL1: 10K; ESP32_WROVER_EAGLE-LTSPICE_R0402
R_RESET: 10K; ESP32_WROVER_EAGLE-LTSPICE_R0402
SENSOR2: BME688; ESP32_WROVER_BME680_PSON80P300X300X100-8N
SJ1: SJ
TP1: TPTP20R; TP20R
TP2, TP3, TP4, TP5, TP6, TP7, TP8, TP9, TP10, TP11, TP12, TP13, TP14, TP15, TP16, TP17: TP; TP20R
U1: W25Q512JVEIQ; SON127P600X800X80-9N
U2: ESP32-C6-WROOM-1-N8; XCVR_ESP32-C6-WROOM-1-N8
U3: DS3231SN#; SOIC127P1032X265-16N
U4: MAX17048G+T10; SON50P200X200X80-9N

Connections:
3V3: C1_BAT2.1, C3.+, C9.1, D7.1 (ANODE), IC1.2 (VDD), IC4.5 (VOUT), J3.2, J4.P4 (VDD), Q2.3 (D), R1.2, R1-PINH1.2, R2-PINH1.2, R5.2, R6.2, R7.2, R8.2, R9.2, R10.2, R_BOOT.2, R_CHANGE.2, R_CL1.2, R_RESET.2, TP16.TP, U1.3 (!WP!(IO2)), U1.7 (!HOLD!/!RESET!(IO3)), U1.8 (VCC), U2.2 (3V3), U3.2 (VCC)
32KHZ: R2-PINH1.1, U2.9 (IO1), U3.1 (32KHZ)
DN: D1.1 (I/O1_1), J2.A7, J2.B7
DP: D1.3 (I/O2_1), J2.A6, J2.B6
EPD_3V3: C7.1, EPD_C5.1, J1.15, J1.16, L1.2, Q2.2 (S), TP17.TP
EPD_3V3_C: Q2.1 (G), R_CL1.1, TP13.TP, U2.18 (IO20)
EPD_BUSY: J1.9, TP9.TP, U2.26 (IO3)
EPD_CS: D6.2, J1.12, R9.1, TP10.TP, U2.11 (IO10)
EPD_DC: J1.11, TP11.TP, U2.5 (IO5)
EPD_RST: J1.10, TP12.TP, U2.21 (IO23)
FLASH_CS: D9.2, R5.1, U1.1 (!CS), U2.12 (IO11)
GDR: J1.2, Q3.1 (G), R4.2
GND: BOOT_BUTTON.1, BOOT_BUTTON.2, C1.2, C1_BAT.2, C1_BAT1.2, C1_BAT2.2, C2.2, C2_BAT.2, C3.-, C4_USB.2, C5.2, C5_USB.2, C6.2, C7.2, C8.2, C9.2, C10.2, C10_SUPERCAP.1, CHANGE_BUTTON.1, CHANGE_BUTTON.2, C_DELAY.2, D1.5 (VBUS), D3.2 (K), D6.1, D8.1, D9.1, D10.1, D11.1, D12.1, EPD_C1.2, EPD_C2.2, EPD_C5.2, EPD_C6.2, EPD_C7.2, EPD_C8.2, EPD_C9.2, EPD_C10.2, EPD_C11.2, EPD_C12.2, IC1.3 (GND), IC4.2 (VSS), J1.8, J1.17, J1.MP1, J1.MP2, J2.A1, J2.A12, J2.B1, J2.B12, J2.MP1, J2.MP2, J2.MP3, J2.MP4, J3.1, J4.G1 (GND_1), J4.G2 (GND_2), J4.G3 (GND_3), J4.G4 (GND_4), J4.P6 (VSS), MCP73831.2 (VSS), R1_PWRUSB.1, R2.1, R2-USB.2, R2-USB1.1, R2_BAT.1, R4.1, RESET_BUTTON.1, RESET_BUTTON.2, SENSOR2.1 (GND), SENSOR2.5 (SDO), SENSOR2.7 (GND), SJ1.1, TP4.TP, TP5.TP, U1.4 (GND), U1.9 (EXP), U2.1 (GND), U2.28 (GND), U2.29_1 (GND), U2.29_2 (GND), U2.29_3 (GND), U2.29_4 (GND), U2.29_5 (GND), U2.29_6 (GND), U2.29_7 (GND), U2.29_8 (GND), U2.29_9 (GND), U3.13 (GND), U4.1 (CTG), U4.4 (GND), U4.6 (QSTRT), U4.9 (EP)
GPIO8: R1.1, U2.10 (IO8)
I2C_PW: C1.1, C2.1, R1-PINH.2, R2-PINH.2, SENSOR2.2 (CSB), SENSOR2.6 (VDDIO), SENSOR2.8 (VDD), U2.17 (IO19)
INT_RTC: R1-PINH1.1, TP15.TP, U2.8 (IO0), U3.3 (SQW/!INT)
IO/BOOT: BOOT_BUTTON.3, BOOT_BUTTON.4, C6.1, R_BOOT.1, U2.15 (IO9)
IO/CHANGE: C10.1, CHANGE_BUTTON.3, CHANGE_BUTTON.4, R_CHANGE.1, U2.23 (IO15)
MISO: D12.2, J4.P7 (DAT0), R8.1, TP6.TP, U1.2 (DO(IO1)), U2.27 (IO2)
MOSI: D11.2, J1.14, J4.P3 (CMD), R7.1, TP7.TP, U1.5 (DI(IO0)), U2.7 (IO7)
unnamed: MCP73831.1 (STAT), R1_BAT.2
unnamed: J2.A5, R2-USB1.2
unnamed: C1_BAT1.1, D2.2 (CATHODE), IC4.1 (VIN), IC4.3 (CE), Q1.2 (S)
unnamed: J2.B5, R2-USB.1
unnamed: CHG_LED.C, R1_BAT.1
unnamed: C4.1, D3.1 (A), D4.2 (K)
unnamed: EPD_C12.1, J1.24
unnamed: MCP73831.5 (PROG), R2_BAT.2
unnamed: C_DELAY.1, IC1.5 (CT)
unnamed: EPD_C10.1, J1.22
unnamed: D7.2 (CATHODE), R_CAPACITOR.2
unnamed: EPD_C8.1, J1.20
unnamed: EPD_C7.1, J1.19
unnamed: EPD_C6.1, J1.18
unnamed: EPD_C1.1, J1.4
unnamed: EPD_C2.1, J1.5
PREVGH: D5.2 (K), EPD_C9.1, J1.21
PREVGL: D4.1 (A), EPD_C11.1, J1.23
RESE: J1.3, Q3.2 (S), R3.2
RESE': R2.2, R3.1, SJ1.2
RESET: C5.1, IC1.1 (VOUT), RESET_BUTTON.3, RESET_BUTTON.4, R_RESET.1, U2.3 (EN)
RTC_RST: U2.16 (IO18), U3.4 (!RST)
RX: TP2.TP, U2.24 (RXD0/GPIO17)
SCK: D10.2, J1.13, J4.P5 (CLK), R6.1, TP8.TP, U1.6 (CLK), U2.6 (IO6)
SCL: J3.4, R2-PINH.1, SENSOR2.4 (SCK), U2.20 (IO22), U3.16 (SCL), U4.7 (SCL)
SDA: J3.3, R1-PINH.1, SENSOR2.3 (SDI), U2.19 (IO21), U3.15 (SDA), U4.8 (SDA)
SRC: C4.2, D5.1 (A), L1.1, Q3.3 (D)
SS_SD: D8.2, J4.P2 (CD/DAT3), R10.1, U2.4 (IO4)
TX: TP1.TP, U2.25 (TXD0/GPIO16)
USB_D+: D1.4 (I/O2_2), U2.14 (IO13)
USB_D-: D1.6 (I/O1_2), U2.13 (IO12)
VBAT: C2_BAT.1, MCP73831.3 (VBAT), Q1.3 (D), TP3.TP, U4.2 (CELL), U4.3 (VDD)
VBUS: C1_BAT.1, C4_USB.1, C5_USB.1, CHG_LED.A, D1.2 (GND), D2.1 (ANODE), MCP73831.4 (VIN), PFMF.050.1.1, Q1.1 (G), R1_PWRUSB.2, TP14.TP
VRTC: C8.1, C10_SUPERCAP.2, R_CAPACITOR.1, U3.14 (VBAT)
VUSB: J2.A4, J2.A9, J2.B4, J2.B9, PFMF.050.1.2

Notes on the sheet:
USB C connector & ESD protection
LDO Voltage Regulator
SD Card
ESP32 C6
Li-Po Battery Charging Controller
E-Paper Drive Circuit
Display Type Selector
E-Paper Display Header
EPD Power
Environmental Sensor BME688
Voltage Supervisor + Reset & Boot / IO Button
Battery Charge Level
External NOR Flash 64MB
SPI ESD Protection Lines
Qwiic / Stemma QT
Test Pads
RTC Module DS3231SN
SD0805S020S1R0
DMG2305UX-7
drawn by: Udățeanu Andreea
112A-TAAR-R03_ATTEND

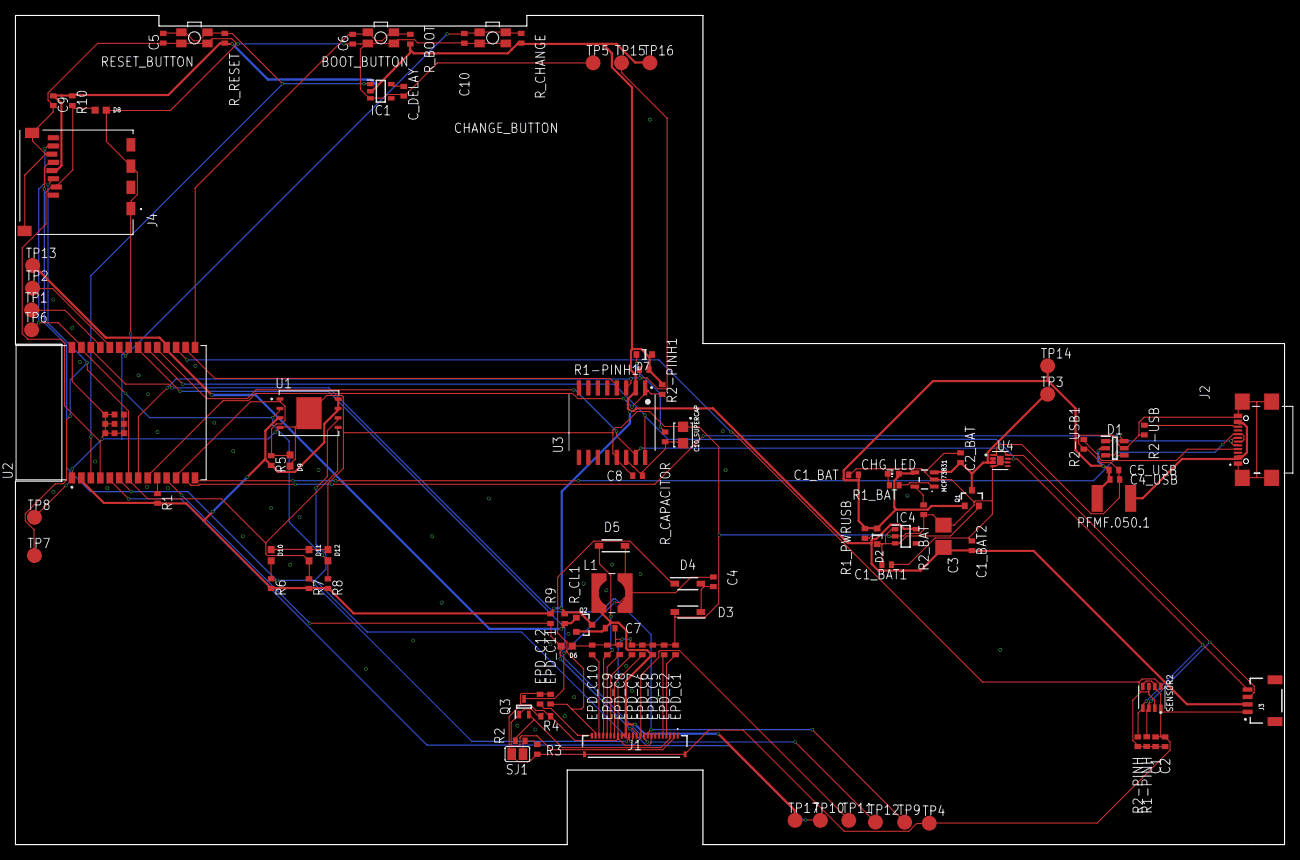
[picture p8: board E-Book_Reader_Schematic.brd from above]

Board: 2 copper layers, 170.2 x 111.2 mm, 103 parts (0 on the bottom side), 55 nets.

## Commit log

2025-04-06 Schematic Files Uploaded
    [BillOfMaterials.csv, E-BookReaderSchematicPCBUdateanuAndreea.brd, E-BookReaderSchematicUdateanuAndreea.sch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]
2025-04-06 Expanded 3D PCB .step file Uploaded
2025-04-13 Schematic Modified Fixes #5 Fixes #6 Fixes #7
    [E-Book_Reader_Schematic.sch]
2025-04-13 PCB Modified Fixes #1 Fixes #2 Fixes #3 Fixes #4
    [E-Book_Reader_Schematic.brd]

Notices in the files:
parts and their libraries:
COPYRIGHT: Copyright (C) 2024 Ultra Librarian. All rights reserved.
